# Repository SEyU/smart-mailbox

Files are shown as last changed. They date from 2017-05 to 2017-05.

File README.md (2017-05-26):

# smart-mailbox

How to start the project

```
git clone <this-repo>
cd <this-repo>
docker-compose up -d
````

If there are changes
```
docker-compose build
docker-compose stop && docker-compose up -d
```

## Interactive SmartMailbox system.
 
Smart Mailbox with high functionality.
 
* Look the number of letters inside your Smart Mailbox.
* Get a history of correspondence received in your dashboard.
* It displays real time status of your Smart Mailbox, controlling the state of the inlet opening and the door.
* Get information about the temperature and humidity of the location of your Smart Mailbox.
* Displays the current month history of maximum minimum temperatures and humidity of the environment your smart mailbox.
 
All from a customizable web easily accessible.
 


## Schema

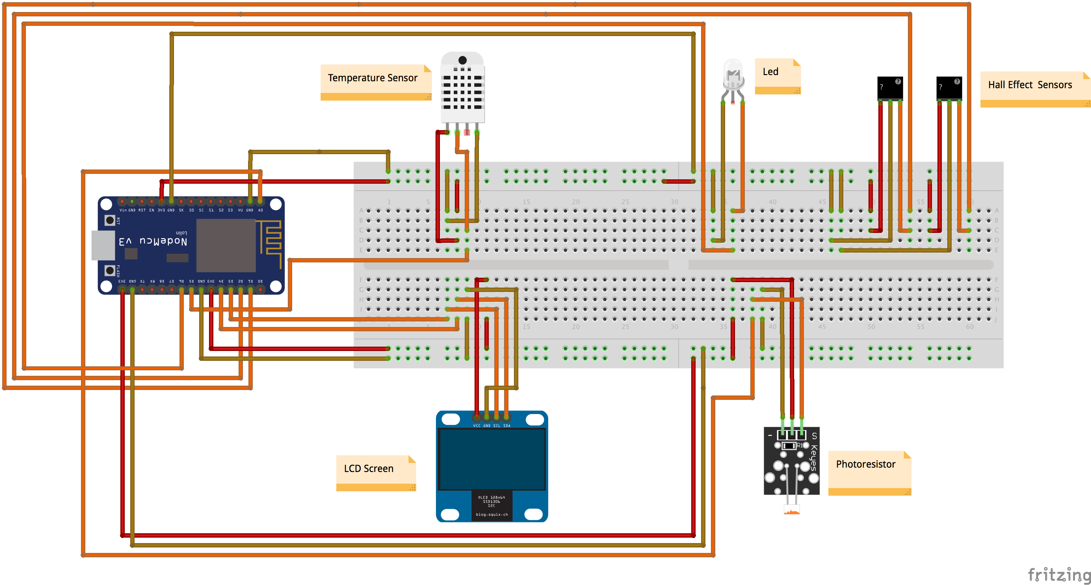
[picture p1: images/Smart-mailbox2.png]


## Wiring

| Component | Pin |
|---|-----|
| Photoresistor | A0  |  
| Door Hall effect sensor | D1  |  
| Pin Hall effect sensor  | D2  |  
| OLED SDA | D3  |
| OLED SCL | D4  |
| DHT22 | D5  |  
| LED | D6  |  

All components operate at 3.3V.

## Project structure

* `iot/platformio.ini`: PlatformIO project configuration and dependencies.
* `iot/src`: Source folder.
    * `iot/src/main.cpp`: Main program.
    * `iot/src/fonts.h`: OLED fonts and icons definitions.
    * `iot/src/config.h.example`: Example wireless and server configuration. Rename to `config.h' on deployment.
* `dashboard/`: Web app to manage the project

### Required libraries

* [ESP8266_SSD1306](https://github.com/squix78/esp8266-oled-ssd1306)
* [DHT22](https://github.com/adafruit/DHT-sensor-library)
* [NTPClient](https://github.com/arduino-libraries/NTPClient)
* [ESPasyncTCP](https://github.com/me-no-dev/ESPAsyncTCP)

If you use PlatformIO, these libraries are already configured on the project.

## Dashboard

For the dashboard we use **Angular.js** as a framework to develop it, as a requirements we don't need anything but a web server like apache or nginx. To change the address of the API within the dashboard you have to change a line in the services/MainService.js file.

```
app.service('MainService', ['$http', function ($http) {

var urlBase = 'http://apiaddress:8080';

...
```

We use a MVC schema to develop the app.

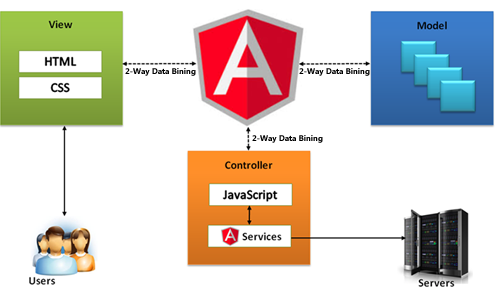
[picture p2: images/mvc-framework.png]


### Dashboard - Google Charts

To draw charts we call the google charts library, with it we draw 2 different kinds of charts.

* Calendar charts:



* Line charts:

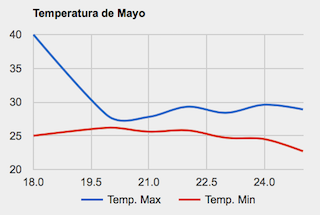
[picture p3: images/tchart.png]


### Dashboard - RealTime statistics

In our dashboard we can control the status of our mailbox (doors and letters) in real time, besides that we can see the temperature and humidity on the fly.

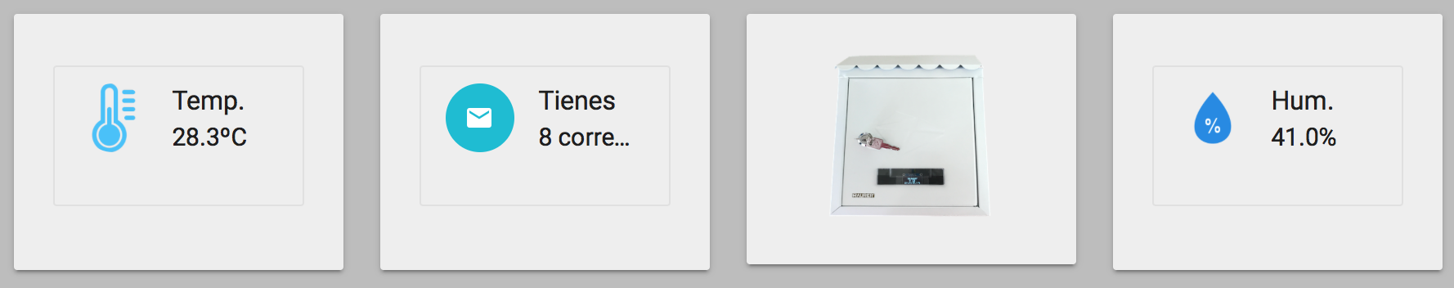
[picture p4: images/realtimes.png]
 

## API 

All communications is done via HTTP REST services. We have an REST service made in Python and Flask. Persistence is achived using MongoDB for storing events and Redis for hadling the state of the doors.

All infraestructure is based in Docker both in development and in production. Our production machine is a Ubuntu Server 16.04 hosted in Azure.

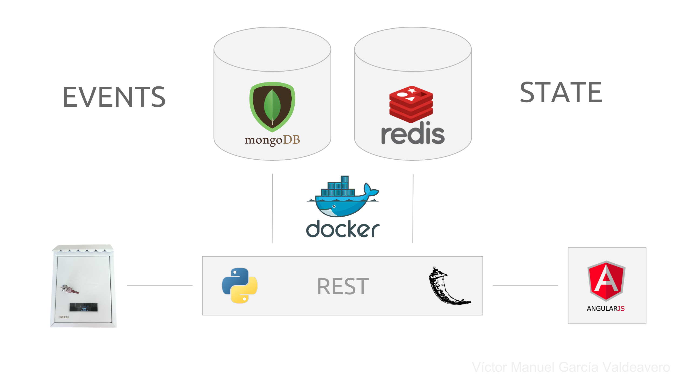
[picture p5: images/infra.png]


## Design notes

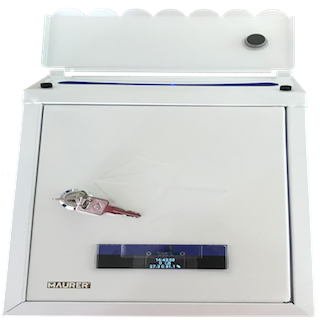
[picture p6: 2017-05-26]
dashboard/img/topOdoorC.png

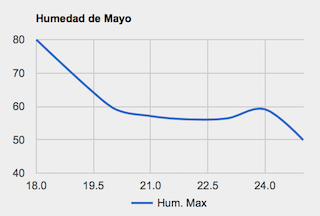
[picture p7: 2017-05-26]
images/hchart.png

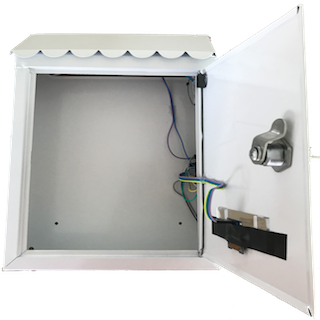
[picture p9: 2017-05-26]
dashboard/img/topCdoorO.png

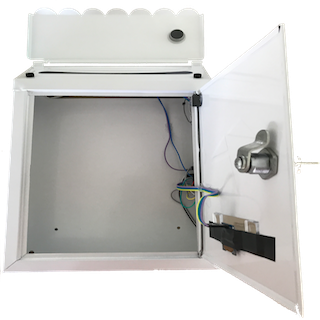
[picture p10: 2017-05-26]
dashboard/img/topOdoorO.png

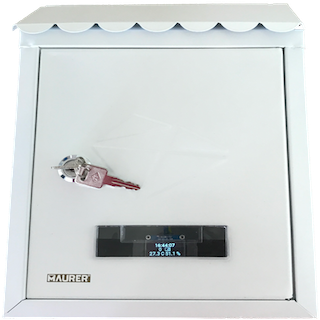
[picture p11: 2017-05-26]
dashboard/img/topCdoorC.png

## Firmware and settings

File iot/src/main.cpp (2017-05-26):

#include <Arduino.h>
#include <Wire.h>
#include <ESP8266WiFi.h>
#include <WiFiUdp.h>
#include <NTPClient.h>
#include <SSD1306.h>
#include <DHT.h>
#include <ESPAsyncTCP.h>
#include <SyncClient.h>
#include "fonts.h"
#include "config.h"

const int dhtPin = D5;
const int ledPin = D6;
const int ldrPin = A0;
const int topPin = D2;
const int doorPin = D1;

const int ledInterval = 100;
const int screenInterval = 1000;
const int dhtInterval = 60000;
const int doorInterval = 1000;
const int ldrThreshold = 100;

int ledMillis = 0;
int screenMillis = 0;
int dhtMillis = 0;
int doorMillis = 0;

float temperature = 0;
float humidity = 0;
int ldrLast = 0;
int mailCount = 0;
bool mailIn = false;

bool topStatus = false;
bool doorStatus = false;

SSD1306 display(0x3c, D3, D4);
WiFiUDP ntpUDP;
NTPClient timeClient(ntpUDP, 7200); // UTC + 2 -> 7200 sec. offset.
DHT dht(dhtPin, DHT22);

void setup() {
  display.init();
  display.flipScreenVertically();
  display.setFont(Roboto_Medium_20);

  display.clear();
  display.setTextAlignment(TEXT_ALIGN_CENTER);
  display.drawString(64, 0, String("Conectando..."));
  display.display();

  WiFi.begin(ssid, password);
  while (WiFi.status() != WL_CONNECTED) {
    delay(500);
  }
  display.drawString(64, 20, "¡Conectado!");
  display.drawString(64, 40, WiFi.localIP().toString());
  display.display();

  timeClient.begin();
  dht.begin();
  pinMode(ledPin, OUTPUT);
  pinMode(ldrPin, INPUT);
  pinMode(topPin, INPUT_PULLUP);
  pinMode(doorPin, INPUT_PULLUP);

  Serial.begin(9600);
}

void notify(String path) {
  unsigned long startMillis = millis();
  SyncClient client;
  if(!client.connect(apiURL, apiPort)){
    Serial.println("Connection failed.");
    return;
  }
  client.setTimeout(2);
  if(client.printf("POST /%s HTTP/1.1\r\nHost: mailbox.clanlr.net\r\nX-Api-Key: %s\r\n\r\n",
                   path.c_str(), apiKey) > 0){
    while(client.connected() && client.available() == 0){
      delay(1);
    }
//    While(client.available()){
//      Serial.write(client.read());
//    }
//    Serial.println("");
    if(client.connected()){
      client.stop();
    }
    Serial.printf("POST /%s OK. Time = %u ms.\n", path.c_str(), millis() - startMillis);
  } else {
    client.stop();
    Serial.println("Send failed.");
    while(client.connected()) delay(1);
  }
}

void loop() {
  unsigned long currentMillis = millis();

  if (currentMillis - ledMillis >= ledInterval) {
    ledMillis = currentMillis;

    if (digitalRead(doorPin)) {
      digitalWrite(ledPin, LOW);
      ldrLast = 0;
      mailCount = 0;
    } else if (digitalRead(topPin)) {
      digitalWrite(ledPin, HIGH);
      if (ldrLast == 0) {
        delay(500);
        ldrLast = analogRead(ldrPin);
        Serial.printf("LDR initial value = %d\n", ldrLast);
      } else {
        int ldrCurr = analogRead(ldrPin);
        if (ldrCurr - ldrLast > ldrThreshold) {
          if (!mailIn) {
            Serial.printf("DEBUG ldrCurr = %d, ldrLast = %d, diff = %d\n", ldrCurr, ldrLast, ldrCurr - ldrLast);
            mailCount += 1;
            mailIn = true;
            notify("letter");
          }
        } else {
          mailIn = false;
        }
      }
    } else {
      digitalWrite(ledPin, LOW);
      ldrLast = 0;
    }
  }

  if (currentMillis - doorMillis >= doorInterval) {
    doorMillis = currentMillis;

    int doorCurr = digitalRead(doorPin);
    int topCurr = digitalRead(topPin);
    if (doorCurr && !doorStatus) {
      doorStatus = true;
      notify("door");
    } else if (!doorCurr && doorStatus) {
      doorStatus = false;
      notify("door/close");
    }
    if (topCurr && !topStatus) {
      topStatus = true;
      notify("top");
    } else if (!topCurr && topStatus) {
      topStatus = false;
      notify("top/close");
    }
  }

  if (currentMillis - screenMillis >= screenInterval) {
    screenMillis = currentMillis;

    timeClient.update();
    display.clear();
    display.setTextAlignment(TEXT_ALIGN_CENTER);
    display.drawString(64, 0, timeClient.getFormattedTime());
    display.drawString(64, 40, String(temperature, 1) + " C " + String(humidity, 1) + " %");
    display.setTextAlignment(TEXT_ALIGN_LEFT);
    display.drawString(40, 20, String(mailCount));
    display.drawXbm(65, 22, mail_width, mail_height, mail_bits);
    display.display();
  }

  if (currentMillis - dhtMillis >= dhtInterval) {
    dhtMillis = currentMillis;

    float h = dht.readHumidity();
    float t = dht.readTemperature();
    if (!isnan(h) && !isnan(t)) {
      humidity = h;
      temperature = t;
    }
    String path;
    notify(String("measures?temp="+ String(temperature, 1) + "&hum=" + String(humidity, 1)));
  }
}

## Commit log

2017-05-17 Prototipo de la funcionalidad del NodeMCU. Principalmente faltan las comunicaciones con la API.
2017-05-18 Esquema Fritz
    [Smart-mailbox.fzz]
2017-05-18 Añadida comunicación con el servidor REST para los eventos de entrada de correo, temperatura y humedad. También experimentando con el método de detección de correo para intentar mejorar su fiabilidad.
2017-05-22 Mejorada la rutina de detección de cartas.
2017-05-22 Notificaciones al servidor para apertura y cerrado de puertas.
2017-05-23 Cambiado el puerto de la API de 8000 a 8080 para poder accedder desde la red de la UAL.
2017-05-23 Datos de la API extraidos a config.h y puerto cambiado a 8080.
2017-05-25 Wiring, project structure and required libraries documentation.
